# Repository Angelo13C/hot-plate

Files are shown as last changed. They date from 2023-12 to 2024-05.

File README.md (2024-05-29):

# Hot plate
An hot plate used to reflow solder electrical components on a PCB.

This is a table of contents:

| Name  | Description |
| --- | --- |
| [Firmware](firmware)  | The software running on the hot plate, written in Rust  |
| [Electronics](electronics)  | The plate that will become hot (which is a PCB) and the controller board that controls the current going to the plate (a separate PCB based on a STM32 microcontroller) |

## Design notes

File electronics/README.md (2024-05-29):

# Electronics
The electronics of this project is divided in 2 parts:
| Name  | Description |
| --- | --- |
| [Plate](hot-plate)  | A plate designed to become hot when current is applied to its 2 terminals  |
| [Controller](controller)  | A controller board that controls how much current goes to the plate above based on a PID controller. It tries to follow a temperature curve to obtain optimal results. |

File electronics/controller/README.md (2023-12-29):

# Electronics
This is the electrical control board on which the firmware runs.

It's based on an `STM32F730R8T6`. The board receives stable `24V` from an external power supply unit and requires around `10A` of current.

On the board there's a switching regulator that converts the `24V` to `3.3V`, which is used by: `thermistors`, `display`, `MLX90614` and microcontroller.

## Schematic
This is the electrical schematic of the board:

Schematic

## PCB
The PCB (dimensions: 52mm x 52mm) has 4 layers (PWR/SIGNAL, GND, GND, PWR/SIGNAL). This is an image of the top layer:



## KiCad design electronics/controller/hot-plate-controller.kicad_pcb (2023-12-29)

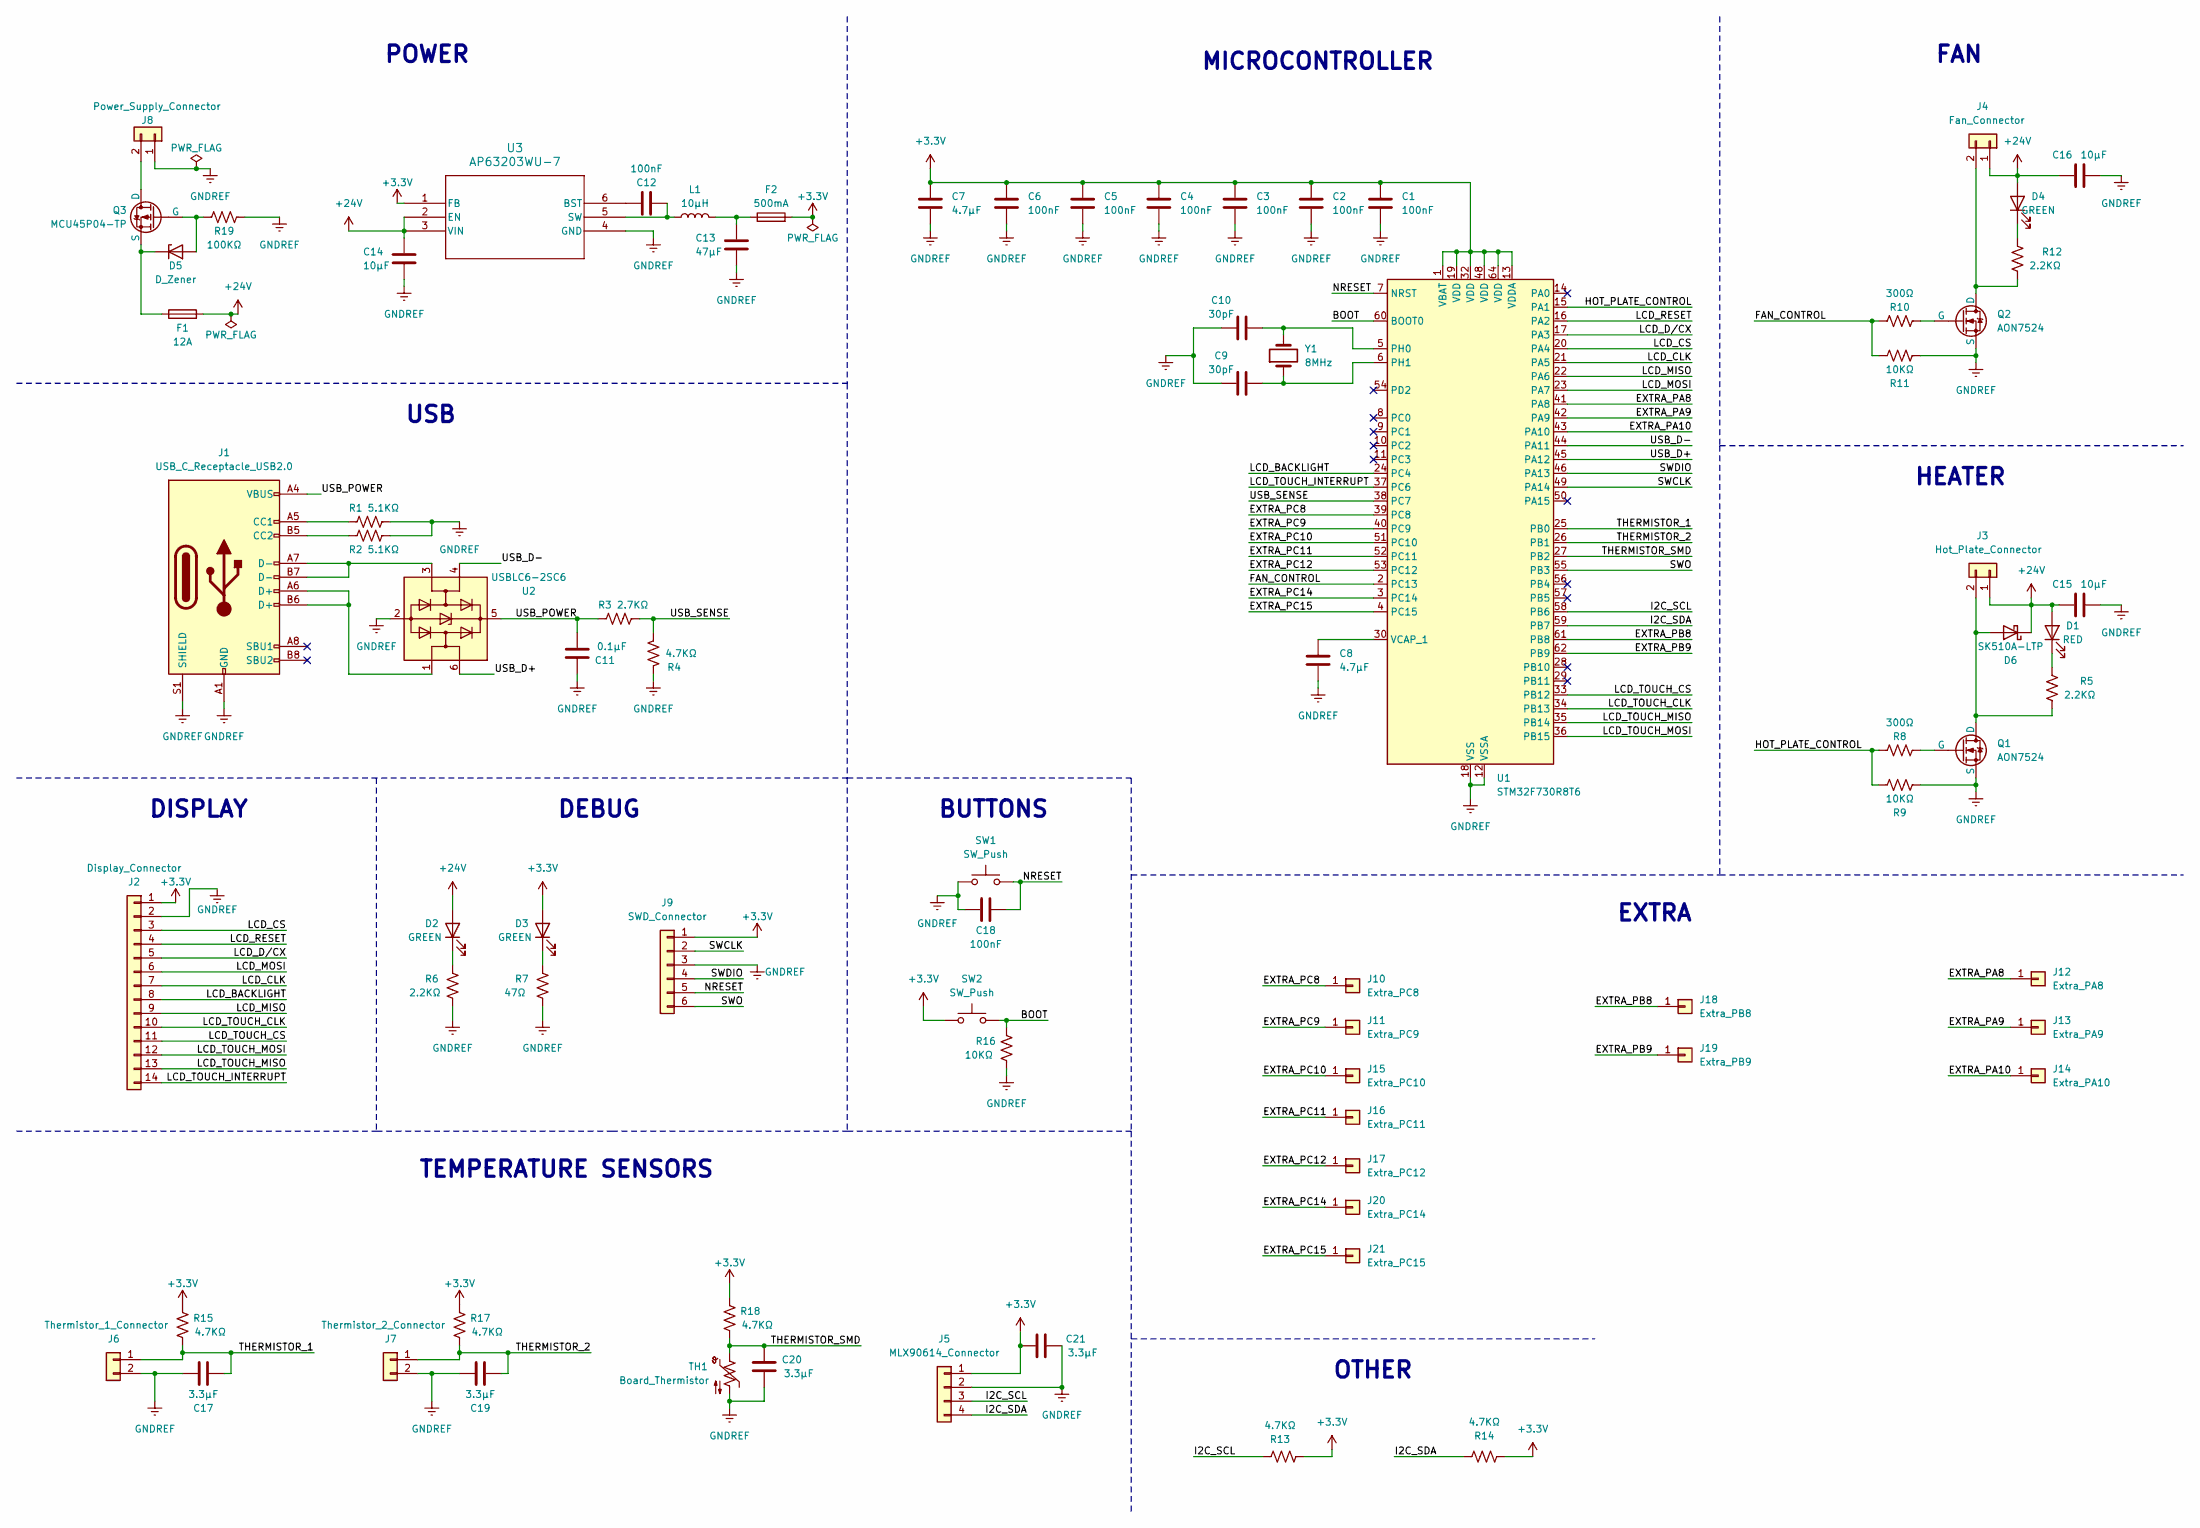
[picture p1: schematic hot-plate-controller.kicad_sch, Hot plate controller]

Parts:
C1, C2, C3, C4, C5, C6, C12, C18: 100nF; C_0805_2012Metric_Pad1.18x1.45mm_HandSolder
C7, C8: 4.7μF; C_0805_2012Metric_Pad1.18x1.45mm_HandSolder
C9, C10: 30pF; C_0805_2012Metric_Pad1.18x1.45mm_HandSolder
C11: 0.1μF; C_0805_2012Metric_Pad1.18x1.45mm_HandSolder
C13: 47μF; C_0805_2012Metric_Pad1.18x1.45mm_HandSolder
C14, C15, C16: 10μF; C_0805_2012Metric_Pad1.18x1.45mm_HandSolder
C17, C19, C20, C21: 3.3μF; C_0805_2012Metric_Pad1.18x1.45mm_HandSolder
D1: RED; LED_0603_1608Metric_Pad1.05x0.95mm_HandSolder
D2, D3, D4: GREEN; LED_0603_1608Metric_Pad1.05x0.95mm_HandSolder
D5: D_Zener; D_SOD-123
D6: SK510A-LTP; SMADO-214AC_LEAD-FRAME_MCC-L
F1: 12A; Fuse_1206_3216Metric_Pad1.42x1.75mm_HandSolder
F2: 500mA; Fuse_1206_3216Metric_Pad1.42x1.75mm_HandSolder
J1: USB_C_Receptacle_USB2.0; USB_C_Receptacle_GCT_USB4085
J2: Display_Connector; PinHeader_1x14_P2.54mm_Vertical
J3: Hot_Plate_Connector; PinHeader_1x02_P2.54mm_Vertical
J4: Fan_Connector; PinHeader_1x02_P2.54mm_Vertical
J5: MLX90614_Connector; PinHeader_1x04_P2.54mm_Vertical
J6: Thermistor_1_Connector; PinHeader_1x02_P2.54mm_Vertical
J7: Thermistor_2_Connector; PinHeader_1x02_P2.54mm_Vertical
J8: Power_Supply_Connector; PinHeader_1x02_P2.54mm_Vertical
J9: SWD_Connector; PinHeader_1x06_P2.54mm_Vertical
J10: Extra_PC8; PinHeader_1x01_P2.54mm_Vertical
J11: Extra_PC9; PinHeader_1x01_P2.54mm_Vertical
J12: Extra_PA8; PinHeader_1x01_P2.54mm_Vertical
J13: Extra_PA9; PinHeader_1x01_P2.54mm_Vertical
J14: Extra_PA10; PinHeader_1x01_P2.54mm_Vertical
J15: Extra_PC10; PinHeader_1x01_P2.54mm_Vertical
J16: Extra_PC11; PinHeader_1x01_P2.54mm_Vertical
J17: Extra_PC12; PinHeader_1x01_P2.54mm_Vertical
J18: Extra_PB8; PinHeader_1x01_P2.54mm_Vertical
J19: Extra_PB9; PinHeader_1x01_P2.54mm_Vertical
J20: Extra_PC14; PinHeader_1x01_P2.54mm_Vertical
J21: Extra_PC15; PinHeader_1x01_P2.54mm_Vertical
L1: 10μH; HPC 5040NF-100M
Q1, Q2: AON7524; DFN-8-1EP_3x3mm_P0.65mm_EP1.55x2.4mm
Q3: MCU45P04-TP; TO-252-2
R1, R2: 5.1KΩ; R_0805_2012Metric_Pad1.20x1.40mm_HandSolder
R3: 2.7KΩ; R_0805_2012Metric_Pad1.20x1.40mm_HandSolder
R4, R13, R14, R15, R17, R18: 4.7KΩ; R_0805_2012Metric_Pad1.20x1.40mm_HandSolder
R5, R6, R12: 2.2KΩ; R_0805_2012Metric_Pad1.20x1.40mm_HandSolder
R7: 47Ω; R_0805_2012Metric_Pad1.20x1.40mm_HandSolder
R8, R10: 300Ω; R_0805_2012Metric_Pad1.20x1.40mm_HandSolder
R9, R11, R16: 10KΩ; R_0805_2012Metric_Pad1.20x1.40mm_HandSolder
R19: 100KΩ; R_0805_2012Metric_Pad1.20x1.40mm_HandSolder
SW1, SW2: SW_Push; SW_LS38J2F-T
TH1: Board_Thermistor; R_0805_2012Metric_Pad1.20x1.40mm_HandSolder
U1: STM32F730R8T6; LQFP-64_10x10mm_P0.5mm
U2: USBLC6-2SC6; SOT-23-6_Handsoldering
U3: AP63203WU-7; AP63203WU-7_DIO
Y1: 8MHz; Crystal_HC49-4H_Vertical

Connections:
+3.3V: C1.1, C2.1, C3.1, C4.1, C5.1, C6.1, C7.1, C21.2, D3.2 (A), F2.2, J2.1, J5.1, J9.1, R13.1, R14.1, R15.1, R17.1, R18.1, SW2.1, U1.1 (VBAT), U1.13 (VDDA), U1.19 (VDD), U1.32 (VDD), U1.48 (VDD), U1.64 (VDD), U3.1 (FB)
+24V: C14.1, C15.1, C16.1, D1.2 (A), D2.2 (A), D4.2 (A), D6.1 (K), F1.2, J3.1, J4.1, U3.2 (EN), U3.3 (VIN)
/BOOT: R16.1, SW2.2, U1.60 (BOOT0)
/EXTRA_PA8: J12.1, U1.41 (PA8)
/EXTRA_PA9: J13.1, U1.42 (PA9)
/EXTRA_PA10: J14.1, U1.43 (PA10)
/EXTRA_PB8: J18.1, U1.61 (PB8)
/EXTRA_PB9: J19.1, U1.62 (PB9)
/EXTRA_PC8: J10.1, U1.39 (PC8)
/EXTRA_PC9: J11.1, U1.40 (PC9)
/EXTRA_PC10: J15.1, U1.51 (PC10)
/EXTRA_PC11: J16.1, U1.52 (PC11)
/EXTRA_PC12: J17.1, U1.53 (PC12)
/EXTRA_PC14: J20.1, U1.3 (PC14)
/EXTRA_PC15: J21.1, U1.4 (PC15)
/FAN_CONTROL: R10.2, R11.2, U1.2 (PC13)
/HOT_PLATE_CONTROL: R8.2, R9.2, U1.15 (PA1)
/I2C_SCL: J5.3, R13.2, U1.58 (PB6)
/I2C_SDA: J5.4, R14.2, U1.59 (PB7)
/LCD_BACKLIGHT: J2.8, U1.24 (PC4)
/LCD_CLK: J2.7, U1.21 (PA5)
/LCD_CS: J2.3, U1.20 (PA4)
/LCD_D/CX: J2.5, U1.17 (PA3)
/LCD_MISO: J2.9, U1.22 (PA6)
/LCD_MOSI: J2.6, U1.23 (PA7)
/LCD_RESET: J2.4, U1.16 (PA2)
/LCD_TOUCH_CLK: J2.10, U1.34 (PB13)
/LCD_TOUCH_CS: J2.11, U1.33 (PB12)
/LCD_TOUCH_INTERRUPT: J2.14, U1.37 (PC6)
/LCD_TOUCH_MISO: J2.13, U1.35 (PB14)
/LCD_TOUCH_MOSI: J2.12, U1.36 (PB15)
/NRESET: C18.2, J9.5, SW1.2, U1.7 (NRST)
/SWCLK: J9.2, U1.49 (PA14)
/SWDIO: J9.4, U1.46 (PA13)
/SWO: J9.6, U1.55 (PB3)
/THERMISTOR_1: C17.2, J6.1, R15.2, U1.25 (PB0)
/THERMISTOR_2: C19.2, J7.1, R17.2, U1.26 (PB1)
/THERMISTOR_SMD: C20.2, R18.2, TH1.1, U1.27 (PB2)
/USB_D+: U1.45 (PA12), U2.6 (I/O1)
/USB_D-: U1.44 (PA11), U2.4 (I/O2)
/USB_POWER: C11.2, J1.A4 (VBUS), J1.A9 (VBUS), J1.B4 (VBUS), J1.B9 (VBUS), R3.1, U2.5 (VBUS)
/USB_SENSE: R3.2, R4.1, U1.38 (PC7)
GNDREF: C1.2, C2.2, C3.2, C4.2, C5.2, C6.2, C7.2, C8.2, C9.1, C10.1, C11.1, C13.2, C14.2, C15.2, C16.2, C17.1, C18.1, C19.1, C20.1, C21.1, J1.A1 (GND), J1.A12 (GND), J1.B1 (GND), J1.B12 (GND), J1.S1 (SHIELD), J2.2, J5.2, J6.2, J7.2, J8.1, J9.3, Q1.3 (S), Q2.3 (S), R1.2, R2.2, R4.2, R6.2, R7.2, R9.1, R11.1, R16.2, R19.2, SW1.1, TH1.2, U1.12 (VSSA), U1.18 (VSS), U1.31 (VSS), U1.47 (VSS), U1.63 (VSS), U2.2 (GND), U3.4 (GND)
unnamed: C13.1, F2.1, L1.2
unnamed: D1.1 (K), R5.1
unnamed: D2.1 (K), R6.1
unnamed: D3.1 (K), R7.1
unnamed: D4.1 (K), R12.1
unnamed: D5.2 (A), Q3.2 (G), R19.1
unnamed: D5.1 (K), F1.1, Q3.3 (S)
unnamed: D6.2 (A), J3.2, Q1.1 (D), R5.2
unnamed: J1.A5 (CC1), R1.1
unnamed: J1.B5 (CC2), R2.1
unnamed: J1.A6 (D+), J1.B6 (D+), U2.1 (I/O1)
unnamed: J1.A7 (D-), J1.B7 (D-), U2.3 (I/O2)
unnamed: J4.2, Q2.1 (D), R12.2
unnamed: J8.2, Q3.1 (D)
unnamed: Q1.2 (G), R8.1
unnamed: Q2.2 (G), R10.1
unnamed: C10.2, U1.5 (PH0), Y1.2
unnamed: C9.2, U1.6 (PH1), Y1.1
unnamed: C8.1, U1.30 (VCAP_1)
unnamed: C12.1, U3.6 (BST)
unnamed: C12.2, L1.1, U3.5 (SW)

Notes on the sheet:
DEBUG
POWER
DISPLAY
MICROCONTROLLER
USB
BUTTONS
HEATER
OTHER
FAN
EXTRA
TEMPERATURE SENSORS

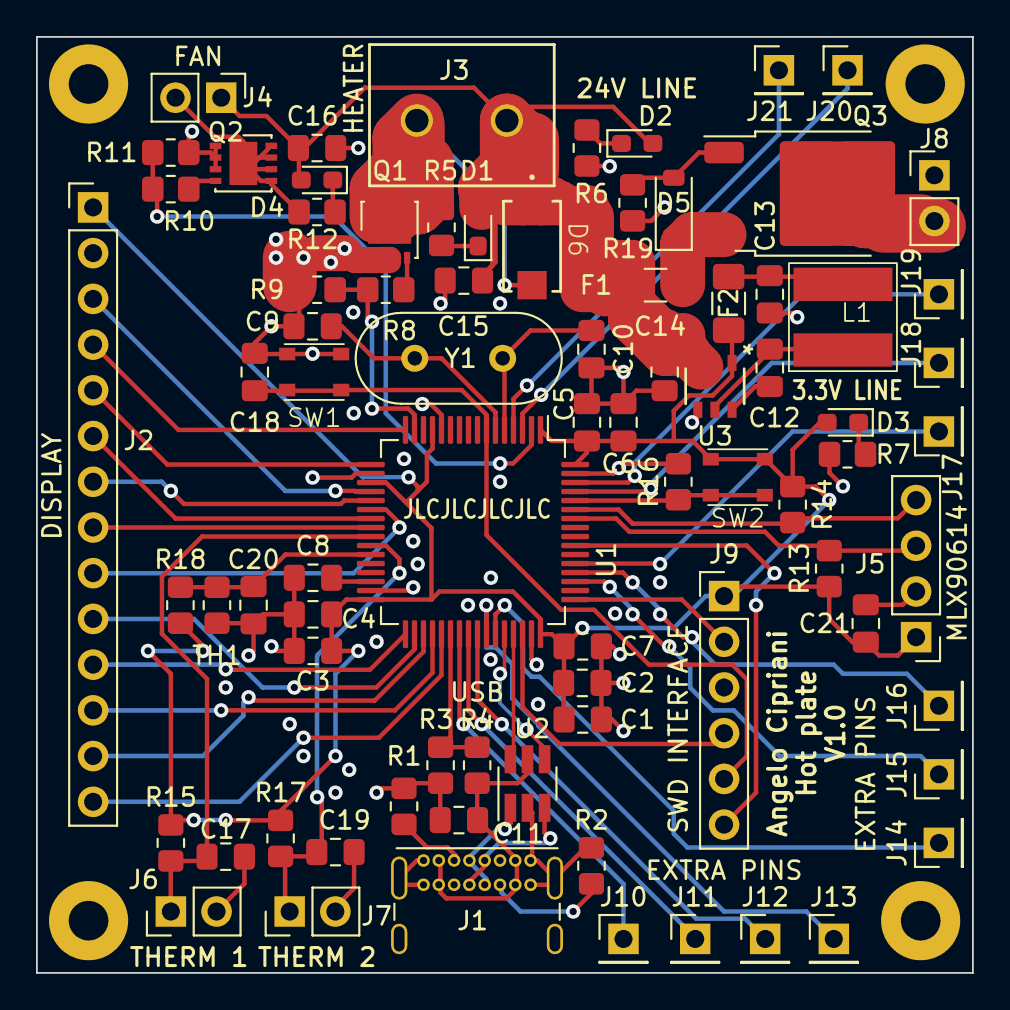
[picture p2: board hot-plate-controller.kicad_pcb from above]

Board: 4 copper layers, 52.0 x 52.0 mm, 80 parts (0 on the bottom side), 64 nets.

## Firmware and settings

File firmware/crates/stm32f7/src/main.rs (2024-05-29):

#![no_std]
#![no_main]

pub mod config;
pub mod peripherals;

use firmware_core::hot_plate::HotPlate;
// pick a panicking behavior
use panic_halt as _; // you can put a breakpoint on `rust_begin_unwind` to catch panics
					 // use panic_abort as _; // requires nightly
					 // use panic_itm as _; // logs messages over ITM; requires ITM support
					 // use panic_semihosting as _; // logs messages to the host stderr; requires a debugger

use cortex_m_rt::entry;
use peripherals::Peripherals;

#[entry]
fn main() -> ! {
	let mut hot_plate = create_hot_plate();

	loop {
		hot_plate.tick().unwrap();
	}
}

fn create_hot_plate() -> HotPlate<Peripherals> {
	let peripherals = Peripherals::from_stm32_peripherals(
		stm32f7xx_hal::pac::Peripherals::take().unwrap(),
		cortex_m::Peripherals::take().unwrap(),
	);
	HotPlate::new(peripherals, config::configuration()).unwrap()
}

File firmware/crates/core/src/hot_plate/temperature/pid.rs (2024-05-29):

use enumset::EnumSet;
use pid::Pid;

use super::safety::{self, TemperatureSafety};
use crate::{
	hot_plate::{
		drivers::{cartridge_heater::CartridgeHeater, thermistor::Thermistor},
		hal::{
			adc::{Adc, AdcPin, ReadPercentageError},
			pwm::PwmPin,
		},
	},
	utils::{
		math::{self, Percentage},
		measurement::temperature::Temperature,
	},
};

/// A [`PID controller`] used to control the temperature of a system in a closed loop.
///
/// To use it, first [`create`] the controller, than whenever you want you can [`choose the target temperature`]
/// and you must continually call [`tick`] to make the controller actually do the work.
///
/// [`PID controller`]: https://en.wikipedia.org/wiki/Proportional%E2%80%93integral%E2%80%93derivative_controller
/// [`create`]: `Self::new`
/// [`choose the target temperature`]: `Self::set_target_temperature`
/// [`tick`]: `Self::tick`
pub struct PidController<CHP: PwmPin, TADC: Adc, TP: AdcPin<TADC>> {
	thermistor: Thermistor<TADC, TP>,
	cartridge_heater: CartridgeHeater<CHP>,
	pid_control: Pid<f32>,
	safety: TemperatureSafety,

	last_current_temperature_sample: Option<Temperature>,
}

impl<CHP: PwmPin, TADC: Adc, TP: AdcPin<TADC>> PidController<CHP, TADC, TP> {
	/// The minimum limit output by the PID control. Take this in consideration when setting the `PidGains`.
	pub const PID_CONTROL_MIN_LIMIT: f32 = 0.;
	/// The maximum limit output by the PID control. Take this in consideration when setting the `PidGains`.
	pub const PID_CONTROL_MAX_LIMIT: f32 = 100.;

	/// Returns a [`PidController`] that will control the `cartridge heater`'s current based on the [`set target temperature`]
	/// and the [`current temperature`] read in the provided `thermistor` using the provided gains.
	///
	/// [`set target temperature`]: `Self::set_target_temperature`
	/// [`current temperature`]: `Self::get_current_temperature`
	pub fn new(
		thermistor: Thermistor<TADC, TP>, cartridge_heater: CartridgeHeater<CHP>, pid_gains: PidGains,
		safety: TemperatureSafety,
	) -> Self {
		let mut pid_control = Pid::new(0., Self::PID_CONTROL_MAX_LIMIT);
		pid_control.p(pid_gains.p, Self::PID_CONTROL_MAX_LIMIT);
		pid_control.i(pid_gains.i, Self::PID_CONTROL_MAX_LIMIT);
		pid_control.d(pid_gains.d, Self::PID_CONTROL_MAX_LIMIT);

		Self {
			thermistor,
			cartridge_heater,
			pid_control,
			safety,
			last_current_temperature_sample: None,
		}
	}

	/// Returns the [`PidGains`] previously set on this PID controller.
	pub fn get_pid_gains(&self) -> PidGains {
		PidGains {
			p: self.pid_control.kp,
			i: self.pid_control.ki,
			d: self.pid_control.kd,
		}
	}

	/// Set the PID gains of this controller. Check [`Self::PID_CONTROL_MIN_LIMIT`] and [`Self::PID_CONTROL_MAX_LIMIT`] to see in what
	/// range the values should be.
	pub fn set_pid_gains(&mut self, pid_gains: &PidGains) {
		self.pid_control.kp = pid_gains.p;
		self.pid_control.ki = pid_gains.i;
		self.pid_control.kd = pid_gains.d;
	}

	/// Reads the current [`Temperature`] of the PID controller.
	///
	/// Returns `Ok(Temperature)` if the read was succesful, otherwise `Err(ReadPercentageError)`.
	pub fn get_current_temperature(&mut self, adc: &mut TADC) -> Result<Temperature, ReadPercentageError<TADC, TP>> {
		match self.thermistor.read_temperature(adc) {
			Ok(temperature) => {
				self.last_current_temperature_sample = Some(temperature);
				Ok(temperature)
			},
			Err(error) => Err(error),
		}
	}

	/// Gets the [`Temperature`] read using [`Self::get_current_temperature`] the last time you called that function.
	///
	/// Returns `None` if [`Self::get_current_temperature`] has never been successfull since the instantation of this
	/// struct.
	pub fn get_last_sample_of_current_temperature(&self) -> Option<Temperature> {
		self.last_current_temperature_sample
	}

	/// Returns the [`Temperature`] the PID controller is trying to reach.
	pub fn get_target_temperature(&self) -> Temperature {
		Temperature::from_kelvin(self.pid_control.setpoint)
	}

	/// Sets the [`Temperature`] the PID controller will try to reach.
	///
	/// # Warning
	/// You need to call [`PidController::tick`] after this to effectively make the PID controller work to reach it.
	pub fn set_target_temperature(&mut self, target_temperature: Temperature) {
		self.pid_control.setpoint(target_temperature.as_kelvin() as f32);
	}

	/// Make the PID controller work to try to reach its [`target temperature`].
	///
	/// [`target temperature`]: `Self::get_target_temperature`
	pub fn tick(&mut self, delta_time: f32, adc: &mut TADC) -> Result<(), TickError> {
		let current_temperature = self
			.get_current_temperature(adc)
			.map_err(|_| TickError::CantReadTemperature)?;

		let safety_errors =
			self.safety
				.is_temperature_safe(current_temperature, self.get_target_temperature(), delta_time);
		if !safety_errors.is_empty() {
			return Err(TickError::ReadTemperatureIsWrong(safety_errors));
		}

		let mut pwm_value = self
			.pid_control
			.next_control_output(current_temperature.as_kelvin() as f32)
			.output;
		pwm_value = math::map(
			pwm_value,
			Self::PID_CONTROL_MIN_LIMIT..=Self::PID_CONTROL_MAX_LIMIT,
			0_f32..=1_f32,
		);

		self.cartridge_heater
			.set_heat_percentage(Percentage::from_0_to_1(pwm_value as f32).unwrap())
			.map_err(|_| TickError::SetCartridgeHeaterPercentage)?;

		Ok(())
	}
}

#[derive(Debug, Clone, Copy, PartialEq, Eq, Hash)]
/// An error that occurred when calling [`tick`] on a PID controller.
///
/// [`tick`]: PidController::tick
pub enum TickError {
	/// It has been impossible to [`read`] the thermistor's temperature.
	///
	/// [`read`]: `Thermistor::read_temperature`
	CantReadTemperature,

	/// The thermistor's `temperature` has been [`read`], but it's an irregular value.
	///
	/// **It could be that the thermistor is damaged, or its connection to the microcontroller is damaged...**
	/// It could also be a false positive: but it's always better to abort the print and turn off the heaters
	/// to prevent fire hazards. Then if it was a false positive, it means that the parameters passed
	/// to [`Safety::new`] are too strict.
	///
	/// [`read`]: `Thermistor::read_temperature`
	/// [`Safety::new`]: `safety::TemperatureSafety::new`
	ReadTemperatureIsWrong(EnumSet<safety::TemperatureError>),

	/// It has been impossible to [`set`] the cartridge heater's heat percentage.
	///
	/// [`set`]: `CartridgeHeater::set_heat_percentage`
	SetCartridgeHeaterPercentage,
}
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

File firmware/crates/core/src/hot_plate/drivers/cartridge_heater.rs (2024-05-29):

use crate::{hot_plate::hal::pwm::PwmPin, utils::math::Percentage};

/// A cartridge heater connected to the microcontroller that can be controlled using the `P` pin.
pub struct CartridgeHeater<P: PwmPin> {
	pin: P,
}

impl<P: PwmPin> CartridgeHeater<P> {
	/// Returns a [`CartridgeHeater`] that can control its heat percentage through the provided `pin`.
	pub fn new(pin: P) -> Self {
		Self { pin }
	}

	/// Sets the `percentage` of current to give to the heater.
	pub fn set_heat_percentage(&mut self, percentage: Percentage) -> Result<(), <P as PwmPin>::Error> {
		self.pin.set_duty_cycle(percentage)
	}
}

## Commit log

2023-12-22 🎉 Initial commit
2023-12-22 🎉 Begin the electronics hot-plate-controller project
    [hot-plate-controller.kicad_pcb, hot-plate-controller.kicad_sch]
2023-12-26 🍱 Add the "Project" symbol library on KiCad
2023-12-26 🍱 Add the "Project" footprint library on KiCad
2023-12-26 🍱 Add the symbols for all the components used in the project on KiCad
2023-12-26 🍱 Add the USB C footprint on KiCad
2023-12-26 🍱 Add the PMOS footprint on KiCad
2023-12-26 🍱 Add the Button footprint on KiCad
2023-12-26 🍱 Add the SOT-23-6 footprint on KiCad
2023-12-26 🍱 Add the Resistor footprint on KiCad
2023-12-26 🍱 Add the footprints for pin headers on KiCad
2023-12-26 🍱 Add the STM32 footprint on KiCad
2023-12-26 🍱 Add the LED footprint on KiCad
2023-12-26 🍱 Add the footprint for an inductor on KiCad
2023-12-26 🍱 Add the footprint for a fuse (1206) on KiCad
2023-12-26 🍱 Add the NMOS footprint on KiCad
2023-12-26 🍱 Add the Crystal oscillator footprint on KiCad
2023-12-26 🍱 Add the footprint for a capacitor (0805) on KiCad
2023-12-26 🍱 Add the D_SOD-123 footprint on KiCad
2023-12-26 🍱 Add the AP63203WU-7 footprint on KiCad
2023-12-26 🎉 Begin the electronics hot-plate project
2023-12-26 🍱 Add the connector footprint to the hot-plate on KiCad
2023-12-26 🍱 Add the connector symbol to the hot-plate on KiCad
2023-12-26 🧑‍💻 Create a Python tool to automatically generate the trace of the hot plate given some parameters
2023-12-27 🍱 Add the mounting hole footprint to the controller in KiCad
2023-12-27 🍱 Add the Fuse_0603 footprint to the controller in KiCad
2023-12-27 🍱 Add the Resistor_1206 footprint to the controller in KiCad
2023-12-27 🍱 Add the SMADO-214AC_LEAD footprint to the controller in KiCad
2023-12-27 🍱 Update the footprint of the button in the controller on KiCad
    The button is now smaller
2023-12-27 🍱 Add the Schottky diode symbol to the controller in KiCad
2023-12-27 🎉 Begin the firmware-stm32 project
    This is based on the start guide at this link: https://github.com/rust-embedded/cortex-m-quickstart
2023-12-27 ⬆️ Upgrade various dependencies of the firmware-stm32 crate
2023-12-27 🎨 Start using rustfmt to format all the code
2023-12-27 🙈 .gitignore some things at the root directory of the firmware project
2023-12-27 🎉 Begin the firmware-core project
2023-12-27 ➕ Add the firmware-core dependency to firmware-stm32
2023-12-29 🍱 Add some symbols to the controller on KiCad
2023-12-29 🍱 Add the footprint of a pin header (1x01) to the controller on KiCad
2023-12-29 🍱 Add the footprint of a pin header (1x06) to the controller on KiCad
2023-12-29 🍱 Add the footprint of a terminal block to the controller on KiCad
2023-12-29 🍱 Modify the footprint of the USB-C receptacle in the controller on KiCad
2023-12-29 🍱 Modify the footprint of the button in the controller on KiCad
2023-12-29 🍱 Modify the "SMADO-214AC_LEAD-FRAME_MCC-L" footprint in the controller on KiCad
2023-12-29 ✨ Create the schematic of the hot-plate
    [hot-plate.kicad_sch]
2023-12-29 ✨ Create the PCB layout of the hot-plate
    [hot-plate.kicad_pcb]
2023-12-29 ✨ Create the whole schematic of the hot-plate-controller
    [hot-plate-controller.kicad_sch]
2023-12-29 ✨ Create the whole PCB layout of the hot-plate-controller
    [hot-plate-controller.kicad_pcb]
2023-12-29 ➕ Add the embedded-hal dependency to firmware-core
2023-12-29 ➕ Add the ringbuffer dependency to firmware-core
2023-12-29 ➕ Add the micromath dependency to firmware-core
2023-12-29 ➕ Add the enumset dependency to firmware-core
2023-12-29 ➕ Add the pid dependency to firmware-core
2023-12-29 ✨ Add some utils functions to firmware-core
2023-12-29 🙈 Gitignore some files in the firmware-stm32f7 crate
2023-12-29 📝 Add a README file to electronics
2023-12-29 👷 Add GitHub CI system
2024-04-08 🙈 Add the fabrication files to the .gitignore
2024-04-08 🔧 Update the project file of the controller in KiCad
2024-05-29 📝 Add a README file to the repository
2024-05-29 📝 Update the README file
2024-05-29 ✨ Add most of the functionalities to the firmware
